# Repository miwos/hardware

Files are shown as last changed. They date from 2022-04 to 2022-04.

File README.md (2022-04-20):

# MIWOS Hardware

## BOM

| Qty | Value | Device | Package | Parts | Description |
| --- | --- | --- | --- | --- | --- |
| 2 | | DIODE-SOD123 | SOD123 | D1, D2 | DIODE |
| 7 | | LED3MM | LED3MM | LED1, LED2, LED3, LED4, LED5, LED6, LED7 | LED |
| 2 | 0.1uF | C-EUC0603 | C0603 | C1, C2 | CAPACITOR, European symbol |
| 2 | 220R | R-EU_R0603 | R0603 | R3, R8 | RESISTOR, European symbol |
| 4 | 35RASMT2BHNTRX | 35RASMT2BHNTRX | SWITCHCRAFT_35RASMT2BHNTRX | MIDI1-IN, MIDI1-OUT, MIDI2-IN, MIDI2-OUT | Conn 3.5MM Stereo Jack F 3 POS Solder RA SMD 3 Terminal 1 Port T/R Check availability |
| 9 | 470R | R-EU_R0603 | R0603 | R2, R5, R10, R19, R20, R21, R22, R23, R24 | RESISTOR, European symbol |
| 4 | 47R | R-EU_R0603 | R0603 | R1, R4, R9, R11 | RESISTOR, European symbol |
| 1 | 614004190021 | 614004190021 | 614004190021 | USB-HUB | USB TYPE A UP RIGHT THT - SHORT TYPE=>ConUSB2 614004190021 |
| 2 | 6N138 | 6N138 | DIP08-SMD | OK1, OK2 | |
| 7 | D6R60F1LFS | D6R60F1LFS | D6R | BUTTON1, BUTTON2, BUTTON3, BUTTON4, BUTTON5, BUTTON6, BUTTON7 | Pushbutton Switch SPST-NO Keyswitch Through Hole Check prices |
| 3 | DFR0647 | DFR0647 | DFR0647 | DISPLAY1, DISPLAY2, DISPLAY3 | |
| 4 | MOUNT_CH | MOUNT_CH | MOUNT_CH32 | P1, P2, P3, P4 | mounting hole |
| 3 | PEC16 | PEC16 | PEC16 | ENCODER1, ENCODER2, ENCODER3 | Encoder 12mm 0detents 20mm Shft Push Momentry Sw 24 Pulse Check prices |
| 1 | TEENSY4.1 | TEENSY4.1 | TEENSY4.1 | TEENSY-41 | |

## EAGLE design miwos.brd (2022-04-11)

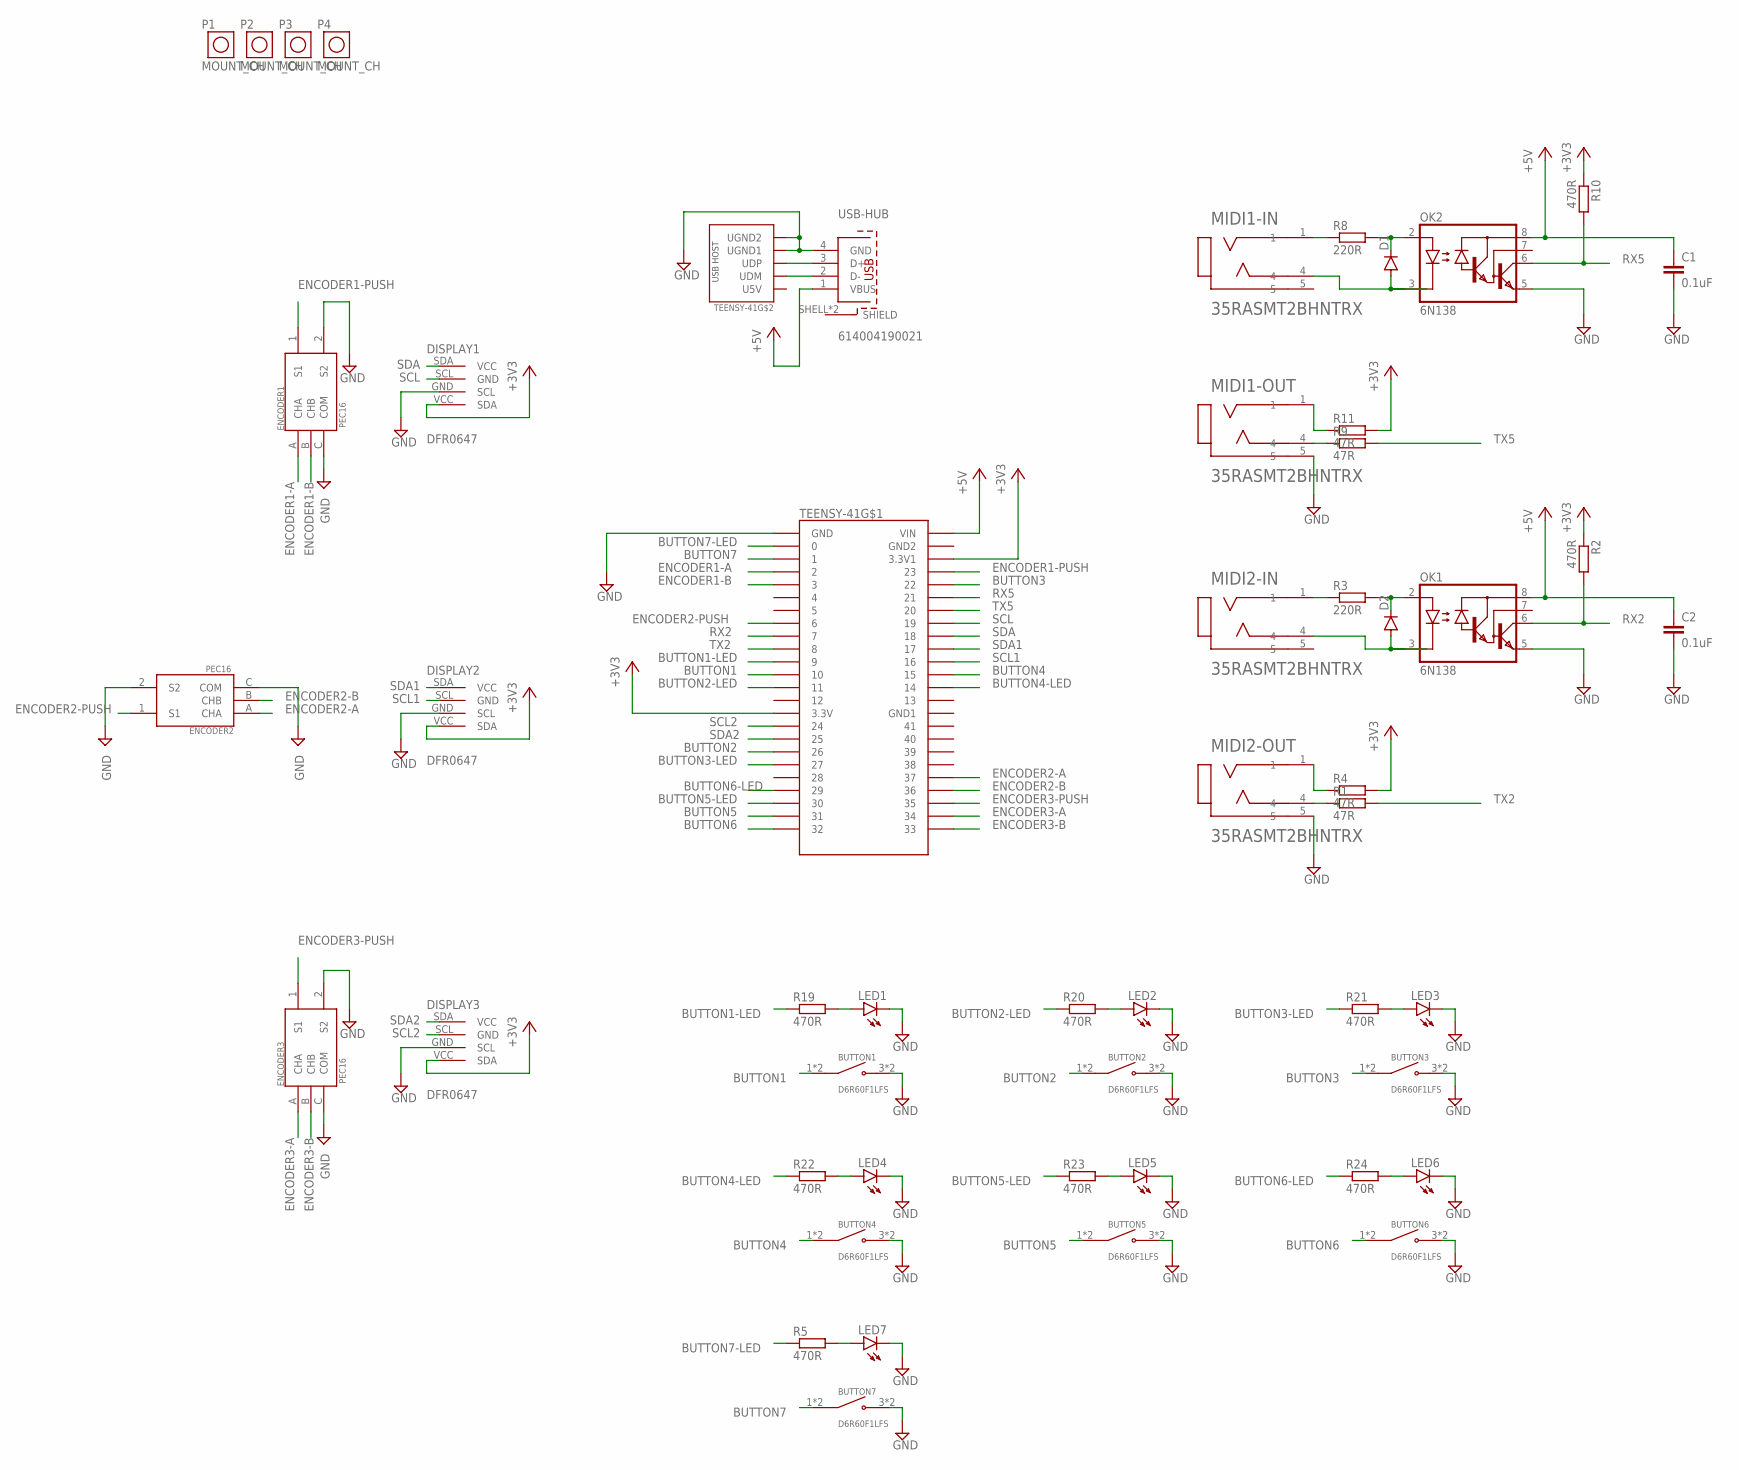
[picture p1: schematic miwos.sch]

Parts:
BUTTON1, BUTTON2, BUTTON3, BUTTON4, BUTTON5, BUTTON6, BUTTON7: D6R60F1LFS; D6R
C1, C2: 0.1uF; C0603
D1, D2: DIODE-SOD123; SOD123
DISPLAY1, DISPLAY2, DISPLAY3: DFR0647
ENCODER1, ENCODER2, ENCODER3: PEC16
LED1, LED2, LED3, LED4, LED5, LED6, LED7: LED3MM
MIDI1-IN, MIDI1-OUT, MIDI2-IN, MIDI2-OUT: 35RASMT2BHNTRX; SWITCHCRAFT_35RASMT2BHNTRX
OK1, OK2: 6N138; DIP08-SMD
P1, P2, P3, P4: MOUNT_CH; MOUNT_CH32
R1, R4, R9, R11: 47R; R0603
R2, R5, R10, R19, R20, R21, R22, R23, R24: 470R; R0603
R3, R8: 220R; R0603
TEENSY-41: TEENSY4.1
USB-HUB: 614004190021

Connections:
+3V3: DISPLAY1.VCC (SDA), DISPLAY2.VCC (SDA), DISPLAY3.VCC (SDA), R2.1, R4.2, R10.1, R11.2, TEENSY-41.3V3 (3.3V), TEENSY-41.3V3_LO (3.3V1)
+5V: C1.1, C2.1, OK1.8 (VCC), OK2.8 (VCC), TEENSY-41.VIN, USB-HUB.1 (VBUS)
BUTTON1: BUTTON1.1 (COM), BUTTON1.2 (COM), TEENSY-41.10/CS (10)
BUTTON1-LED: R19.1, TEENSY-41.9
BUTTON2: BUTTON2.1 (COM), BUTTON2.2 (COM), TEENSY-41.26
BUTTON2-LED: R20.1, TEENSY-41.11/MOSI (11)
BUTTON3: BUTTON3.1 (COM), BUTTON3.2 (COM), TEENSY-41.22/A8 (22)
BUTTON3-LED: R21.1, TEENSY-41.27
BUTTON4: BUTTON4.1 (COM), BUTTON4.2 (COM), TEENSY-41.15/A1 (15)
BUTTON4-LED: R22.1, TEENSY-41.14/A0 (14)
BUTTON5: BUTTON5.1 (COM), BUTTON5.2 (COM), TEENSY-41.31/A12 (31)
BUTTON5-LED: R23.1, TEENSY-41.30
BUTTON6: BUTTON6.1 (COM), BUTTON6.2 (COM), TEENSY-41.32
BUTTON6-LED: R24.1, TEENSY-41.29
BUTTON7: BUTTON7.1 (COM), BUTTON7.2 (COM), TEENSY-41.1/TX (1)
BUTTON7-LED: R5.1, TEENSY-41.0/RX (0)
ENCODER1-A: ENCODER1.A (CHA), TEENSY-41.2
ENCODER1-B: ENCODER1.B (CHB), TEENSY-41.3
ENCODER1-PUSH: ENCODER1.1 (S1), TEENSY-41.23/A9 (23)
ENCODER2-A: ENCODER2.A (CHA), TEENSY-41.37
ENCODER2-B: ENCODER2.B (CHB), TEENSY-41.36
ENCODER2-PUSH: ENCODER2.1 (S1), TEENSY-41.6
ENCODER3-A: ENCODER3.A (CHA), TEENSY-41.34
ENCODER3-B: ENCODER3.B (CHB), TEENSY-41.33
ENCODER3-PUSH: ENCODER3.1 (S1), TEENSY-41.35
GND: BUTTON1.3 (NO), BUTTON1.4 (NO), BUTTON2.3 (NO), BUTTON2.4 (NO), BUTTON3.3 (NO), BUTTON3.4 (NO), BUTTON4.3 (NO), BUTTON4.4 (NO), BUTTON5.3 (NO), BUTTON5.4 (NO), BUTTON6.3 (NO), BUTTON6.4 (NO), BUTTON7.3 (NO), BUTTON7.4 (NO), C1.2, C2.2, DISPLAY1.GND (SCL), DISPLAY2.GND (SCL), DISPLAY3.GND (SCL), ENCODER1.2 (S2), ENCODER1.C (COM), ENCODER2.2 (S2), ENCODER2.C (COM), ENCODER3.2 (S2), ENCODER3.C (COM), LED1.K (C), LED2.K (C), LED3.K (C), LED4.K (C), LED5.K (C), LED6.K (C), LED7.K (C), MIDI1-OUT.5, MIDI2-OUT.5, OK1.5 (GND), OK2.5 (GND), TEENSY-41.GND, TEENSY-41.GND-U1 (UGND1), TEENSY-41.GND-U2 (UGND2), USB-HUB.4 (GND)
unnamed: TEENSY-41.UD- (UDM), USB-HUB.2 (D-)
unnamed: TEENSY-41.UD+ (UDP), USB-HUB.3 (D+)
unnamed: LED7.A, R5.2
unnamed: D1.C, OK2.2 (A), R8.2
unnamed: D1.A, MIDI1-IN.4, OK2.3 (C)
unnamed: MIDI1-IN.1, R8.1
unnamed: MIDI1-OUT.4, R9.1
unnamed: MIDI1-OUT.1, R11.1
unnamed: D2.C, OK1.2 (A), R3.2
unnamed: D2.A, MIDI2-IN.4, OK1.3 (C)
unnamed: MIDI2-IN.1, R3.1
unnamed: MIDI2-OUT.4, R1.1
unnamed: MIDI2-OUT.1, R4.1
unnamed: LED1.A, R19.2
unnamed: LED2.A, R20.2
unnamed: LED3.A, R21.2
unnamed: LED4.A, R22.2
unnamed: LED5.A, R23.2
unnamed: LED6.A, R24.2
RX2: OK1.6 (VO), R2.2, TEENSY-41.7
RX5: OK2.6 (VO), R10.2, TEENSY-41.21/A7 (21)
SCL: DISPLAY1.SCL (GND), TEENSY-41.19/A5/SCL (19)
SCL1: DISPLAY2.SCL (GND), TEENSY-41.16/A2 (16)
SCL2: DISPLAY3.SCL (GND), TEENSY-41.24
SDA: DISPLAY1.SDA (VCC), TEENSY-41.18/A4/SDA (18)
SDA1: DISPLAY2.SDA (VCC), TEENSY-41.17/A3 (17)
SDA2: DISPLAY3.SDA (VCC), TEENSY-41.25
TX2: R1.2, TEENSY-41.8
TX5: R9.2, TEENSY-41.20/A6 (20)

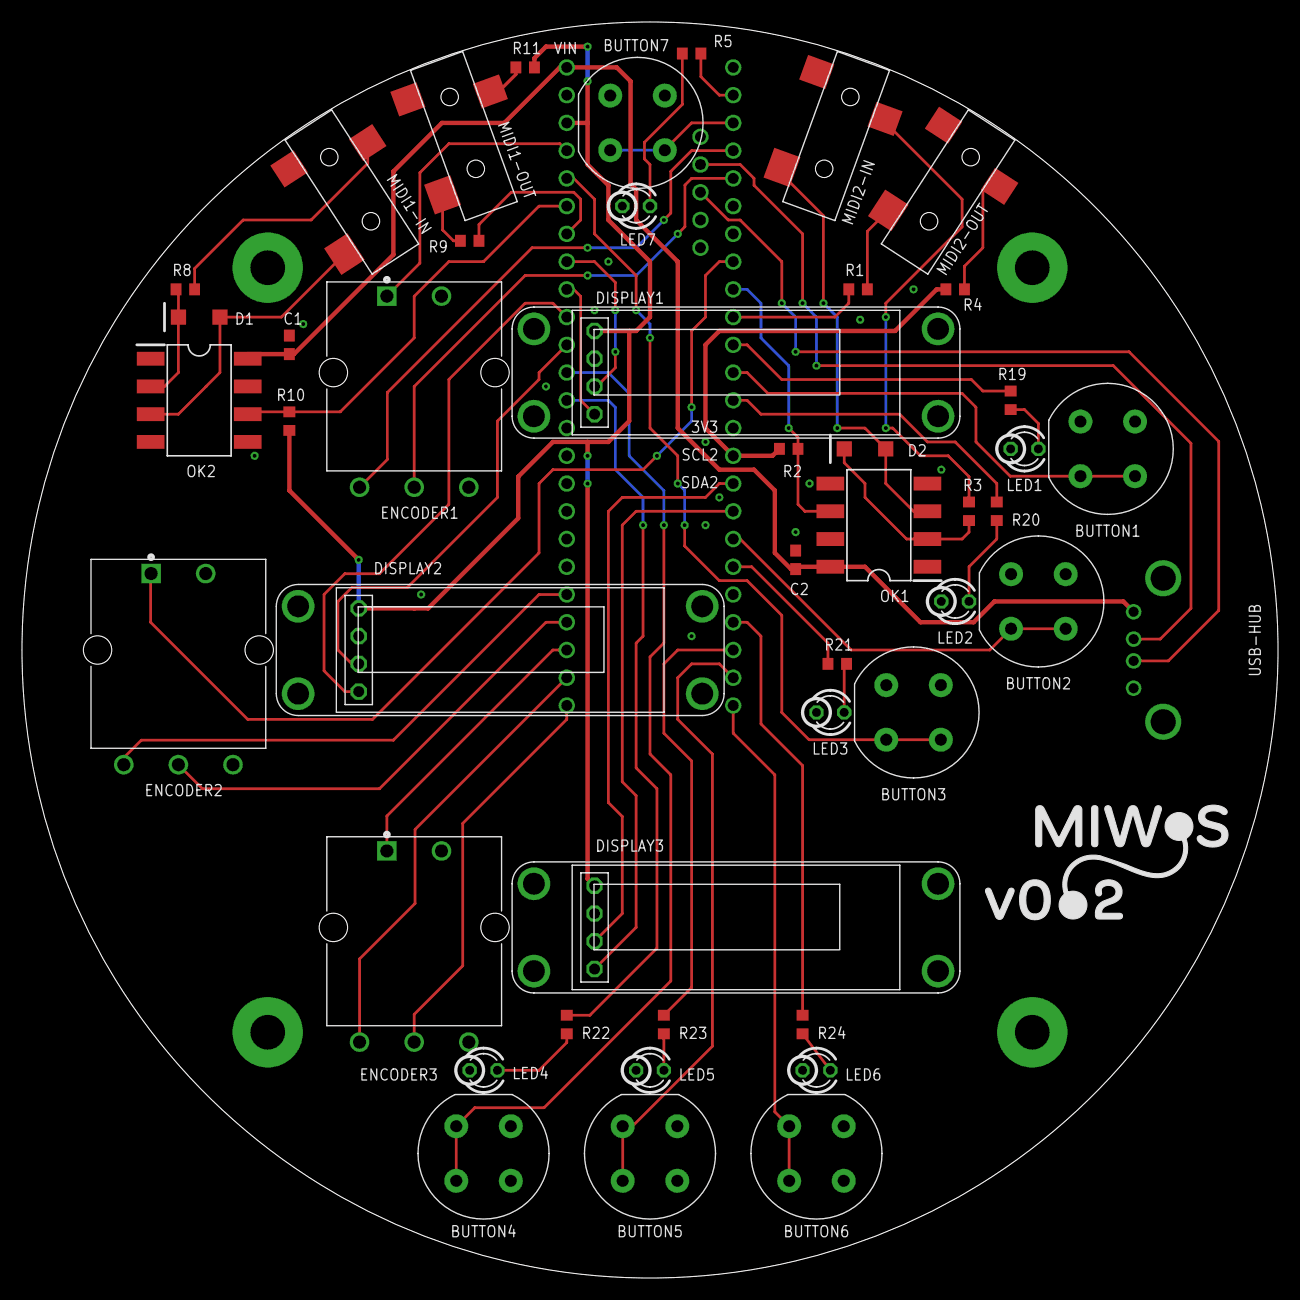
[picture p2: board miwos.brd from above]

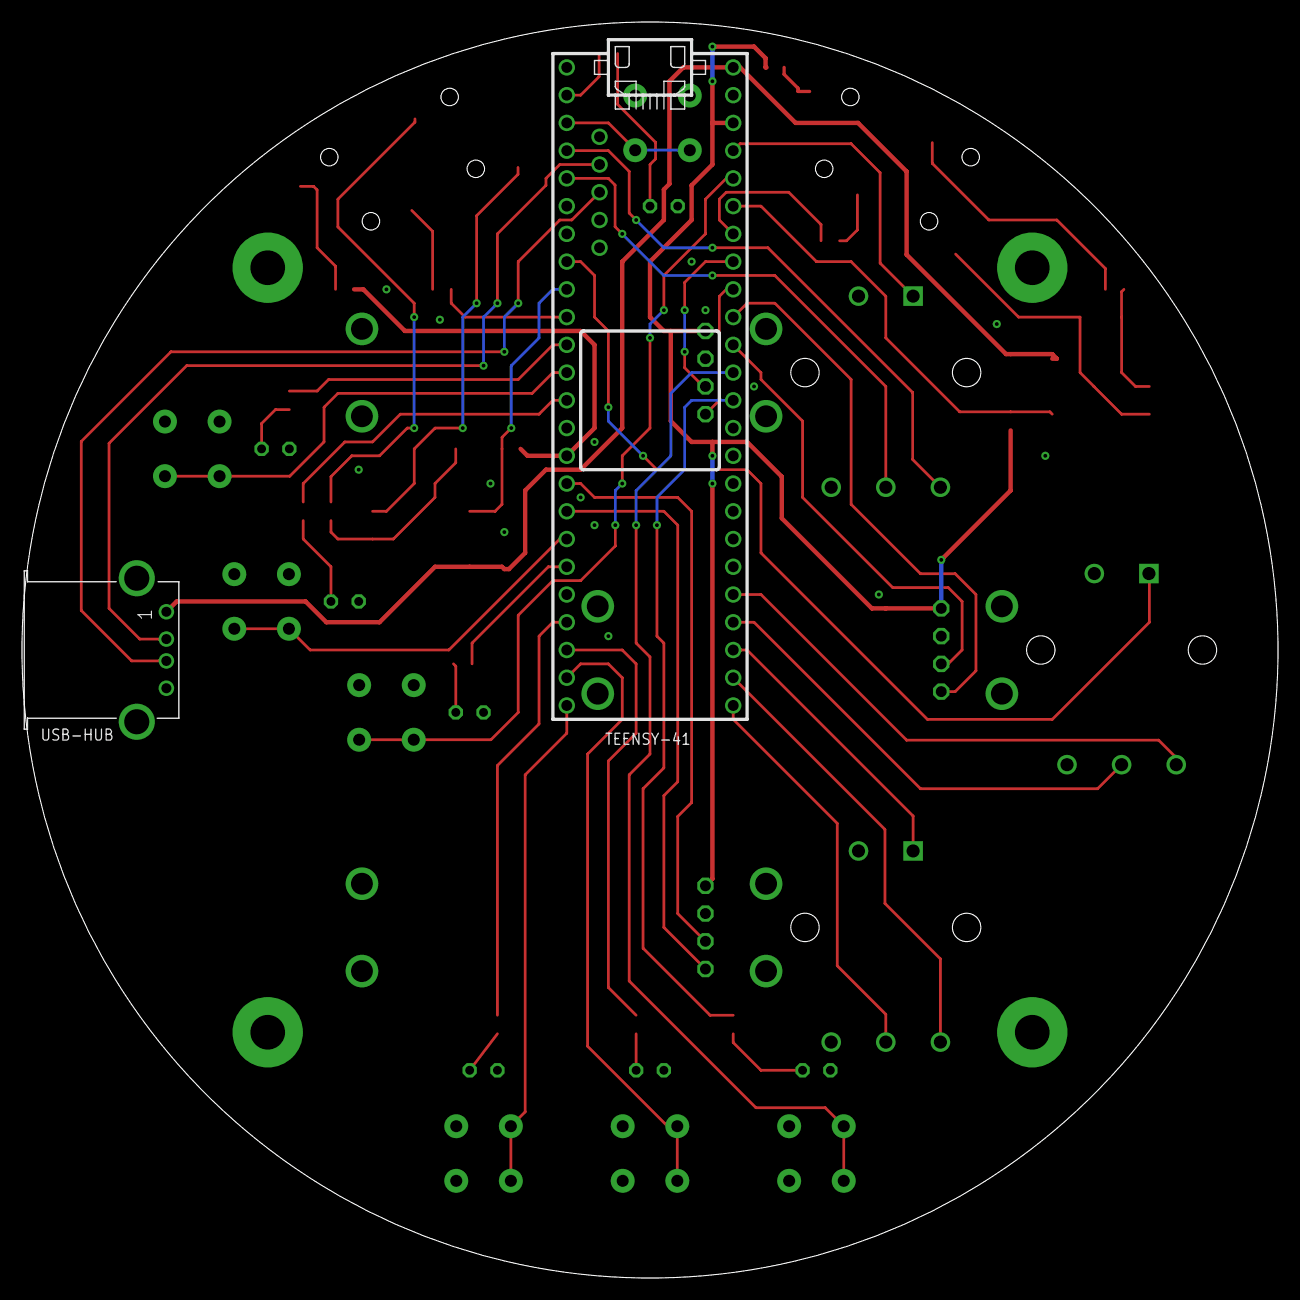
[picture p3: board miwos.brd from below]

Board: 2 copper layers, 115.0 x 115.0 mm, 51 parts (2 on the bottom side), 55 nets.

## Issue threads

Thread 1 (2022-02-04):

Names not printed correctly

arnoson, 2022-02-04:
`R16`, `R11`, `SCL1`, `R9`

Closed 2022-03-28.

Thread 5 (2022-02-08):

Wrong Encoder wiring

arnoson, 2022-02-08:
Pin order is A B C, not A C B

Closed 2022-03-15.

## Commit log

2021-12-06 Use lorenz's version
    [miwos.brd, miwos.sch]
2021-12-06 Wire encoders
    [miwos.brd, miwos.sch]
2021-12-10 Small fixes
    [miwos.brd]
2021-12-16 Refactor, add button LEDs
    [miwos.brd, miwos.sch]
2021-12-17 Add encoder LEDs, don't wire them for now
    [miwos.brd, miwos.sch]
2021-12-17 Wire encoder LEDs
    [miwos.brd, miwos.sch]
2022-01-04 Use center origin, small fixes
    [miwos.brd]
2022-01-04 Place labels, small fixes
    [miwos.brd, miwos.sch]
2022-01-04 Optimize ratsnest
    [miwos.brd]
2022-01-06 Fix DRC errors
    [miwos.brd, miwos.sch]
2022-01-15 Small fixes, add logo
    [miwos.brd, miwos.sch]
2022-01-17 Add gerber
2022-02-04 Add bom, fix #2
    [bom.csv]
2022-03-15 Fix wrong encoder wiring
    [miwos.brd, miwos.sch]
2022-03-15 Update to illuminated D6R buttons
    [miwos.brd, miwos.sch]
2022-03-15 Rearrange midi jacks and encoders/displays
    [miwos.brd]
2022-03-16 Use DFR0647 displays
    [miwos.brd, miwos.sch]
2022-03-18 Use 6N138 SMD footprint
    [miwos.brd, miwos.sch]
2022-03-18 Add shift/menu button
    [miwos.brd, miwos.sch]
2022-03-18 Small changes
    [miwos.brd]
2022-03-19 Update bom
    [bom.csv]
2022-03-28 Use non-illuminated buttons, add mounting holes
    [miwos.brd, miwos.sch]
2022-03-31 Various changes
    [miwos.brd, miwos.sch]
2022-04-06 Use TRS midi
    [miwos.brd, miwos.sch]
2022-04-11 Various changes, add mounting holes
    [miwos.brd, miwos.sch]
2022-04-11 Rotate LEDs
    [miwos.brd, miwos.sch]
2022-04-11 Add logo
    [miwos.brd]
